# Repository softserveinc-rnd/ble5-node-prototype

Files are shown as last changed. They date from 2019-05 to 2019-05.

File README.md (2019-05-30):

# BLE5 node for prototyping

## Hardware Design

The designed system is built around Nordic nRF52840 module that is used as a main
communication and processing unit. 
Nordic Semiconductor’s nRF52840 Bluetooth Low Energy (BLE) System-on-Chip
(SoC) — the high-end variant of Nordic’s nRF52 Series of high-performance
Bluetooth 5-certified SoCs — brings a production-ready, multiprotocol wireless
IoT solution to the market with the full Bluetooth 5 support and support for Bluetooth
mesh and Thread.

The SoC offers the capabilities and flexibility to support a broad range of networked,
connected products for wearables, gaming, VR/AR, as well as home and industrial IoT applications
thanks to a wide range of features and peripherals.

The high-end nRF52840 SoC, based on Nordic’s proven nRF52 Series architecture,
is the first single-chip solution to bring all of the benefits of Bluetooth 5 to the market.
The key advantages of Bluetooth 5 compared to the previous implementations of the BLE specification
include: 2× on-air raw data bandwidth (2 Mb/s); 4× range; 8× broadcasting ability with advertising
extensions that increase the advertising packet payload size to 251 bytes; and an improved channel
coexistence algorithm.

The nRF52840 SoC uses a 64-MHz, 32-bit Arm Cortex M4F processor, floating point, and DSP performance
to meet the demands of challenging wireless applications. The SoC can also operate from the power
supplies above 5 V, such as rechargeable battery power sources.

Other features include a new radio architecture with a +8-dBm on-chip PA, 1-MB flash and 256-kB RAM,
IEEE 802.15.4 (including Thread), ANT, Zigbee, and proprietary 2.4-GHz wireless technologies;
a full-speed USB 2.0 controller; and a host of peripherals including a quad-SPI interface.
In terms of security, the SoC incorporates an Arm CryptoCell-310 cryptographic accelerator.
Extensive crypto-ciphers and key generation and storage options are also available.

There is a set of sensors to measure ambient and usage conditions: 

1. Temperature, humidity for monitoring environment (HTS221).
2. Inertial Measurement Unit(IMU) Accelerometer, gyroscope for monitoring node position, movement and fall detection (LSM6DSM).
3. Pressure sensor for altitude monitoring(LPS22HBTR, also can be used for navigation purposes)  
4. Lighting intensity sensor (OPT3001).

These sensors use I2C bus for communication with Nordic MCU.

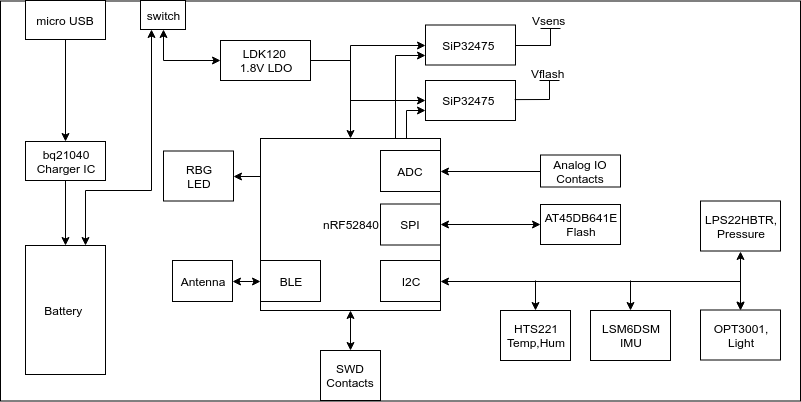
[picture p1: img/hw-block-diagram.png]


The 1.8V LDO is used to power the system from LiPo battery. All the components were selected to run from low voltage level.
There are 2 power switches on the board that are controlled by Nordic chip. These switches are used to power sensors and flash memory.
To minimize power consumption during the sleep mode they can be turned off.

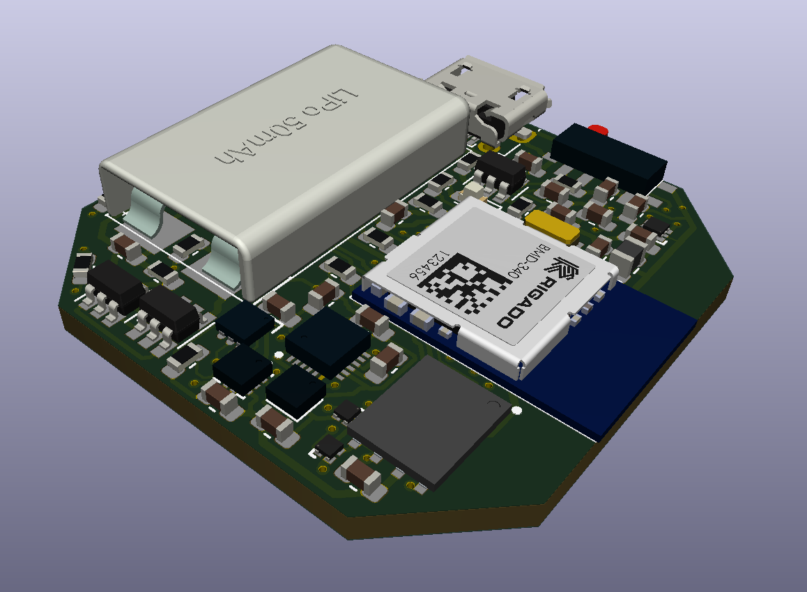
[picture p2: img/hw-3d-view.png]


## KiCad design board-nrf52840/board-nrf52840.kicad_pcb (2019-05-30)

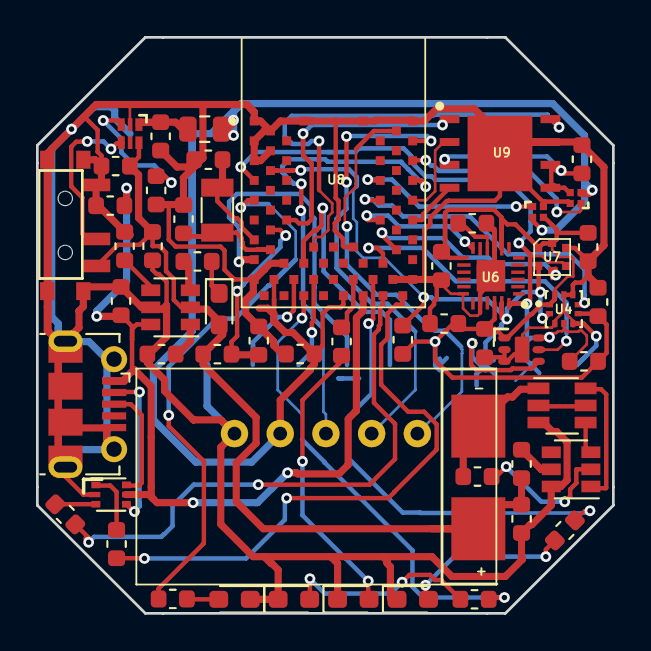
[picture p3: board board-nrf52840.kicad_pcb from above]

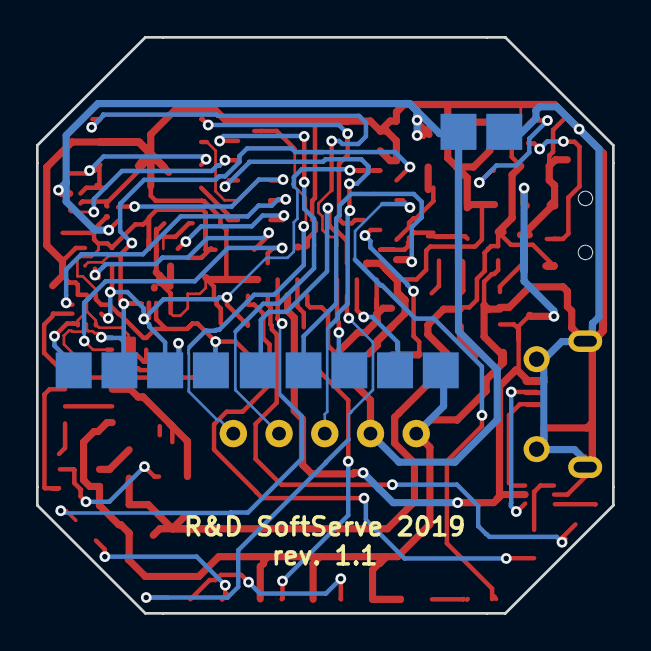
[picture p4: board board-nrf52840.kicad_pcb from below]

Board: 2 copper layers, 32.0 x 32.0 mm, 59 parts (4 on the bottom side), 56 nets.

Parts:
BT1: Battery; BATT-xx1220
C1, C3, C6: 1uF; C_0603_1608Metric
C2, C14: 0.1; C_0603_1608Metric
C4: 100nF; C_0603_1608Metric
C5, C9, C10, C11, C12, C17: 0.1uF; C_0603_1608Metric
C7: 4.7; C_0603_1608Metric
C8: 0.01; C_0603_1608Metric
C13: 4.7uF; C_0603_1608Metric
C15, C16: 6pF; C_0603_1608Metric
D1: LED; LED_0603_1608Metric_Pad1.05x0.95mm_HandSolder
D2: LED_RED; LED_0603_1608Metric_Pad1.05x0.95mm_HandSolder
D3: LED_GREEN; LED_0603_1608Metric_Pad1.05x0.95mm_HandSolder
D4: LED_BLUE; LED_0603_1608Metric_Pad1.05x0.95mm_HandSolder
D5: LED_YELLOW; LED_0603_1608Metric_Pad1.05x0.95mm_HandSolder
J1: USB_OTG; USB_Micro-B_Molex-105017-0001
J2: SWD
J3: Alternative_power; external_power
J4: Conn_01x05_Female; Pogo_5_pins
J5: I2C_sensors; 4x_pins
L1: 330 OHM @ 100MHz; L_0805_2012Metric
Q1: SMC8205AS; TSOT-23-6
R1, R4: 10k; R_0603_1608Metric
R2: 1.5k; R_0603_1608Metric
R3: 100R; R_0603_1608Metric
R5: 1k; R_0603_1608Metric
R6: 1M; R_0603_1608Metric
R7: 220k; R_0603_1608Metric
R8, R9: 4.7k; R_0603_1608Metric
R10, R11, R12, R13: 220R; R_0603_1608Metric
R14, R15: 27R; R_0603_1608Metric
SW1: SW_SPDT_GND; PCM12SMTR
U1: bq21040; SOT-23-6
U2: DW01; SOT-23-6
U3: USBLC6-2P6; SOT-666
U4: LPS22HBTR; LGA10R50P2X3_200X200X80
U6: Val**; ICM-20948
U7: HTS221; HLGA-6L
U8: BMD-340-A-R; BMD340AR
U9: AT45DB641E-MHN-Y; SON127P600X500X60-9N-D
U10, U12: SiP32475; μDFN-4L_1_mm_x_1 mm
U11: OPT3001; USON_PACKAGE
U13: LDK120_; DFN6L
Y1: Crystal; Crystal_SMD_3215-2pin_3.2x1.5mm

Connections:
+1V8: C7.1, L1.1, U13.1
Analog_1_P0.03: J4.2, U8.19
Analog_2_P0.05: J4.3, U8.21
Analog_3_P0.02: J4.4, U8.15
Analog_4_P0.04: J4.5, U8.20
DRDY: U7.3, U8.32
FLASH_PWR_EN: U8.41, U12.1
GND: C1.2, C2.2, C3.2, C4.1, C5.1, C6.2, C7.2, C8.2, C9.1, C10.1, C11.1, C12.1, C13.1, C14.2, C15.1, C16.1, C17.1, D2.1, D3.1, D4.1, D5.1, J1.5, J1.6, J2.1, J3.1, J4.1, J5.1, Q1.3, R1.2, R4.2, R7.2, SW1.1, SW1.4, U1.5, U2.6, U3.2, U4.3, U4.5, U4.8, U4.9, U6.9, U6.18, U6.20, U6.25, U7.5, U8.1, U8.2, U8.3, U8.4, U8.5, U8.16, U8.18, U8.29, U8.30, U8.45, U8.46, U8.47, U8.55, U9.7, U9.9, U10.4, U11.2, U11.3, U12.4, U13.2
I2C_SCL: J5.3, R8.1, U4.2, U6.23, U7.2, U8.6, U11.4
I2C_SDA: J5.2, R9.1, U4.4, U6.24, U7.4, U8.7, U11.6
INT1_IMU: U6.12, U8.56
INT_DTR: U4.7, U8.57
INT_OPT3004: U8.28, U11.5
unnamed: BT1.2, Q1.1, R5.2
unnamed: C8.1, U13.3
unnamed: C12.2, U6.10
unnamed: D1.1, R2.1
unnamed: D2.2, R10.1
unnamed: D3.2, R11.1
unnamed: D4.2, R12.1
unnamed: D5.2, R13.1
unnamed: J1.2, U3.4
unnamed: J1.3, U3.6
unnamed: Q1.2, Q1.5
unnamed: Q1.4, U2.3
unnamed: Q1.6, U2.1
unnamed: R1.1, U1.1
unnamed: R2.2, U1.3
unnamed: R3.1, U2.5
unnamed: R4.1, U1.4
unnamed: R5.1, U2.2
unnamed: R14.2, U8.67
unnamed: R15.2, U8.68
unnamed: SW1.2, U13.4
P0.09: R13.2, U8.25
P0.11: R12.2, U8.27
P0_0: C15.2, U8.13, Y1.1
P0_1: C16.2, U8.14, Y1.2
P0_28: R10.2, U8.9
P1_14: R11.2, U8.63
RESET: J2.3, U8.39
SENS_PWR_EN: U8.58, U10.1
SPI_MISO: U8.53, U9.8
SPI_MOSI: U8.52, U9.1
SPI_NSS: U8.35, U9.4
SPI_SCK: U8.37, U9.2
SWDCLK: J2.4, U8.43
SWDIO: J2.5, U8.44
USB_N: R14.1, U3.3
USB_P: R15.1, U3.1
VBUS: C1.1, C2.1, J1.1, U1.6, U3.5, U8.66
VCC: C13.2, J2.2, J3.2, L1.2, U8.17, U8.65, U10.2, U12.2
VCCQ: C5.2, C9.2, C10.2, C11.2, C17.2, J5.4, R8.2, R9.2, U4.1, U4.6, U4.10, U6.8, U6.13, U6.22, U7.1, U7.6, U10.3, U11.1
VDDF: C14.1, U9.3, U9.5, U9.6, U12.3
V_BAT: BT1.1, C3.1, C4.2, C6.1, D1.2, R3.2, R6.1, SW1.3, U1.2, U13.6
V_BAT_LEV: R6.2, R7.1, U8.12

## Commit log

2019-05-30 Added board schematic and pcb
    [board-nrf52840.kicad_pcb, board-nrf52840.sch]
2019-05-30 Fixed 3d models and footptints
    [board-nrf52840.kicad_pcb, board-nrf52840.sch]
2019-05-30 Fixed Crystal 3D model
    [board-nrf52840.kicad_pcb]
